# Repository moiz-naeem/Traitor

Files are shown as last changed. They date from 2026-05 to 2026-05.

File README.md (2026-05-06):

***

# Traitor Air Defence System 
Its a fully automatic desktop air defence turret powered by a Raspberry Pi Pico. 

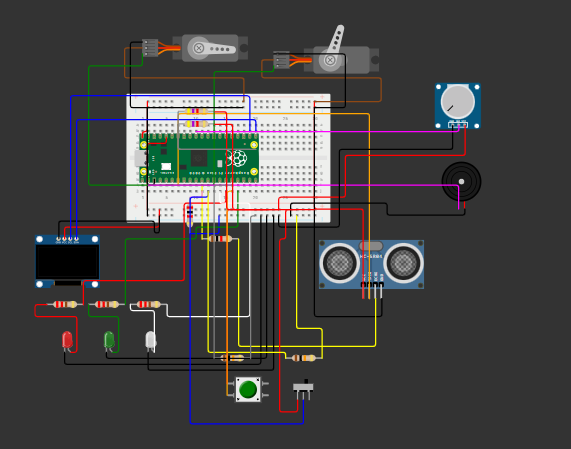
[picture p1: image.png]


Basically, this system spins a sensor around to look for enemys. If it sees something closer then the limit, it double checks to make sure its not a glitch. If the target is real, it sounds a loud alarm and uses a second servo to pull the trigger and launch a dart. You can also turn off the firing and just use it as a alarm.

## How it Works 
The code is written in MicroPython and uses a state machine. It has different moods:
* **IDLE:** System is armed but sleeping.
* **SCANNING:** The scan servo sweeps back and forth. The ultrasonic sensor send pulses to check distance.
* **CONFIRM:** If it spots something, it stops and checks 3 times to make sure the target is actually their.
* **ALERT:** FREAK OUT MODE! Red light turns on, buzzer screams and if your in LAUNCH mode, the trigger servo fires.
* **COOLDOWN:** Takes a 5 second break so it does not just keep shooting forever, then goes back to scanning.

## Hardware Components 
Here is the list of things you need to build this:
* **Raspberry Pi Pico** (Main brain)
* **2x Micro Servos** (One for looking around, one for the trigger)
* **1x HC-SR04 Ultrasonic Sensor** (The main sensor that acts as eyes of the system)
* **1x SSD1306 OLED Display (I2C)** (Shows real time state and sensor's data)
* **1x 5V Magnetic Buzzer** (For the alarm)
* **1x NPN Transistor (like 2N2222)** (Very important! Used as a switch so the buzzer does not burn out the Pico pin)
* **1x Potentiometer** (Twisty knob to change how far the sensor looks)
* **1x Push Button** (Main power switch)
* **1x Slide Switch** (To change between ALARM ONLY and LAUNCH mode)
* **3x LEDs** (Red for danger, Green for scanning, White for power)
* **Resistors:** 
  * 3x 220 Ohm (for LEDs)
  * 2x 10k Ohm (Pull-down for switches)
  * 2x 4.7k Ohm (Pull-up for OLED I2C)
  * 1x 1k Ohm & 1x 2k Ohm (Voltage divider to step down the 5V Echo pin to 3.3V so Pico does not break)

## Pin Mapping 
Make sure you wire everything exact like this or the code does not works. 

| Component | Pico Pin | Notes |
| :--- | :--- | :--- |
| **Scan Servo** | `GP3` | PWM out (50Hz) |
| **Trigger Servo** | `GP4` | PWM out (50Hz) |
| **Ultrasonic TRIG** | `GP5` | Sends the sound pulse |
| **Ultrasonic ECHO**| `GP8` | Hears the bounce (Voltage divider is amust here) |
| **Buzzer** | `GP1` | Connect to transistor base with 1k resistor |
| **Mode Switch** | `GP9` | Changes fire mode (needs 10k pull-down) |
| **Power Button** | `GP12` | Main on/off toggle |
| **Power LED (White)**| `GP10` | Shows if system is active |
| **Alert LED (Red)** | `GP11` | Turns on when target locked |
| **Scan LED (Green)** | `GP13` | Blinks when looking around |
| **OLED SCL** | `GP16` | I2C Clock (needs 4.7k pull-up to 3.3v) |
| **OLED SDA** | `GP17` | I2C Data (needs 4.7k pull-up to 3.3v) |
| **Potentiometer** | `GP26` | ADC to read the twisty knob |

## Setup Instructions 
1. Wire all the components on your breadboard using the pin mapping above. 
2. Make sure you put the 100uF capacitor across the 5V power rails so the servos dont crash the Pico when they move
3. Connect the Pico to your computer.
4. Open Thonny IDE.
5. Go to `Tools > Manage Packages` and install `micropython-ssd1306` so the screen works.
6. Copy the python code into a file called `main.py` on the Pico.
7. Unplug from computer, plug into battery bank, and press the power button to start defending your desk

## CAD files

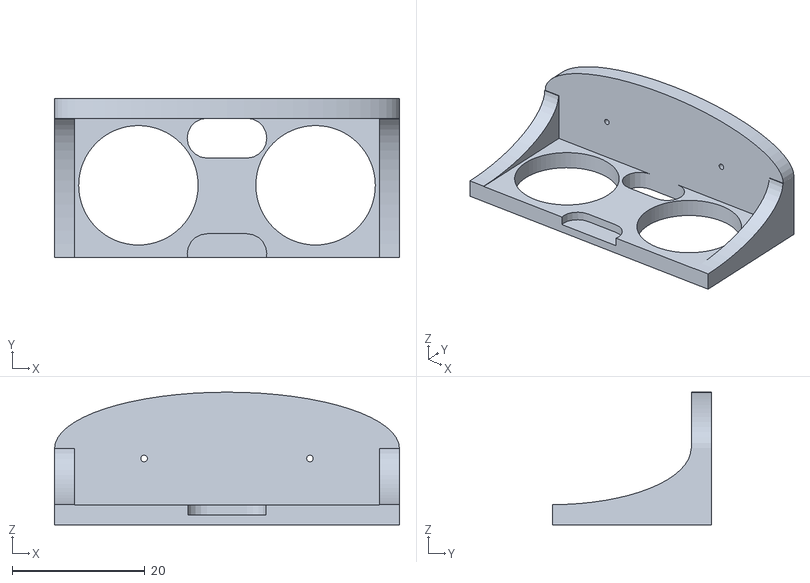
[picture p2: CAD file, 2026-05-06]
HC-SR04 - 9G micro servo bracket.stl
52.0 x 24.0 x 20.0

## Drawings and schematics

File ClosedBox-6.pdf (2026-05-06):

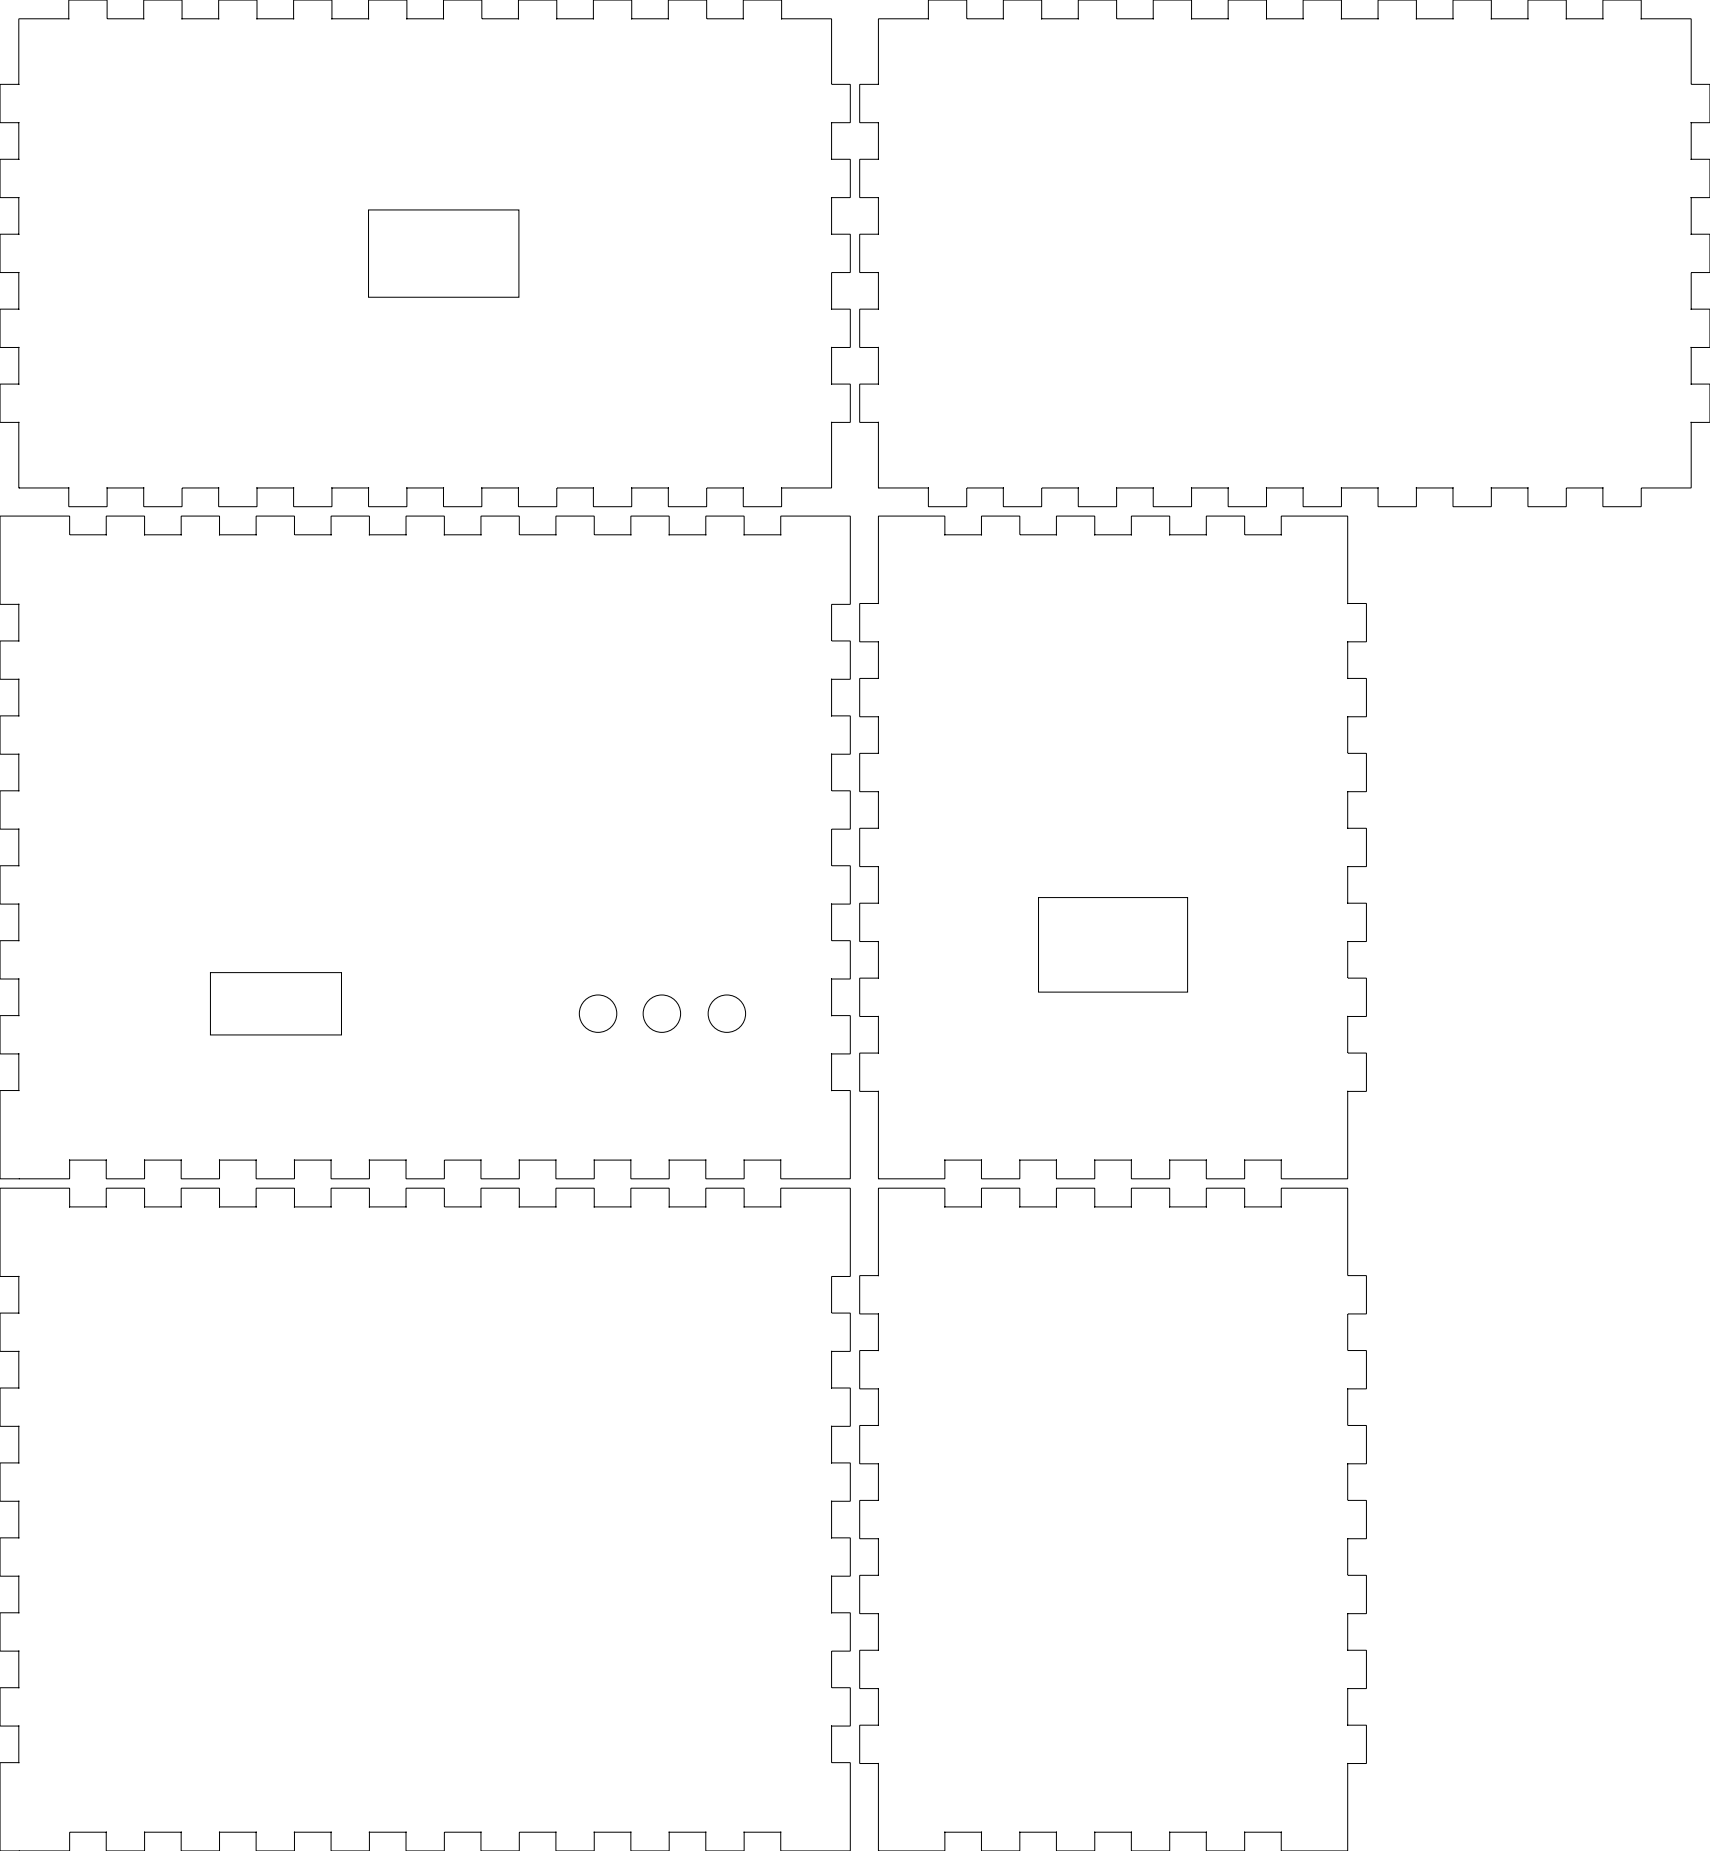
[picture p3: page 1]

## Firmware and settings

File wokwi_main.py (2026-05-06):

# ============================================================
#  Traitor Traitor Air Defence System — MicroPython Firmware
#  Hardware: Raspberry Pi Pico  
#  Author:   Moiz Ul Rehman
#
#  Below is my code for the air defence turret. 
#  Basically it spins ultrasonic sensor around to look for things in the way. 
#  If something gets to close, it double checks,
#  and sounds the alarm. If I flip the switch, it also moves a 
#  second servo to launch a dart at the detected obj 
#
#  Gpio mapping:
#    Pin 3  -> scanner servo that spins left and right 
#    Pin 4  -> launcher servo that pulls the trigger
#    Pin 5  -> ultrasonic trig 
#    Pin 8  -> ultrasonic echo 
#    Pin 1  -> buzzer for the alarm
#    Pin 9  -> slide switch to choose ALARM or LAUNCH mode
#    Pin 12 -> Big main power button
#    Pin 11 -> Red LED (danger light)
#    Pin 13 -> Green LED (scanning/safe light)
#    Pin 10 -> White LED (tells us system is turned on)
#    Pin 16 -> OLED screen SCL clock pin
#    Pin 17 -> OLED screen SDA data pin
#    Pin 26 -> potentiometer to change distance limit
# ============================================================

from machine import Pin, PWM, ADC, I2C
import time

# ============================================================
#  Screen stuff. 
#  Sometimes the screen library is missing depending on which IDE 
#  you are using and it crashes the whole code. So I put a try/except here. 
#  If it cant find the screen code, it just skips it and prints to the serial debig
# ============================================================
try:
    import ssd1306
    _HAS_SSD1306 = True
except ImportError:
    _HAS_SSD1306 = False
    print("[WARN] ssd1306 not found — OLED disabled")

# Setting up the servo motors. They need a 50 frequency to work right.
servo_scan    = PWM(Pin(3));  servo_scan.freq(50)
servo_trigger = PWM(Pin(4));  servo_trigger.freq(50)

# Trigger and echo of ultrasonic sensor 
trig = Pin(5, Pin.OUT)
echo = Pin(8, Pin.IN)    

# The buzzer needs a crazy high frequency to sound really annoying
buzzer = PWM(Pin(1))
buzzer.freq(2730)
buzzer.duty_u16(0) 

# Setting up all the leds, slider switch and power button
mode_sw = Pin(9, Pin.IN, Pin.PULL_DOWN)
btn_power = Pin(12, Pin.IN)
led_red   = Pin(11, Pin.OUT)
led_green = Pin(13, Pin.OUT)
led_power = Pin(10, Pin.OUT)

# I2C wires so the pico can talk to the oled, frq at 40kHz
try:
    i2c = I2C(0, sda=Pin(16), scl=Pin(17), freq=400000)
except Exception as e:
    i2c = None
    print(f"[WARN] I2C init failed: {e}")

# This is the twisty knob pin
pot = ADC(26)

# before proceeding , check if the screen is actually connected and working
HAS_OLED = False
if _HAS_SSD1306 and i2c is not None:
    try:
        oled = ssd1306.SSD1306_I2C(128, 64, i2c)
        HAS_OLED = True
        print("[BOOT] OLED OK")
    except Exception as e:
        print(f"[WARN] OLED failed: {e}")


def servo_set_us(pwm_obj, us):
    """
    Sets the servo position using microsecond pulse widths.
    microPython's duty_u16() takes 0-65535 siince the PWM frequency is 50Hz 
    a full period is 20000us. Formula: (Pulse / Period) * Max_Duty.
    """
    duty = int(us / 20000.0 * 65535)
    pwm_obj.duty_u16(duty)

def angle_to_us(degrees):
    """
    Maps a physical angle 0-180 to a PWM pulse width in microseconds.
    """
    degrees = max(0, min(180, degrees))
    # 500us -->  0 degres and 2500us --> 180 deg.
    return int(500 + (degrees / 180.0) * 2000) 


def get_distance_cm():
    """
    Calculates distance using the HC-SR04 ultrasonic sensor.
    P.S. : I foudn the math below in a doc blog but I forget where.
    Sound travels at 343m/s. The calculation for distance in cm is:
    distance = (time* speed of sound) / 2
    simplified constant: 1 / (0.0343 / 2) -. 58.3.
    """
    trig.value(0)
    time.sleep_us(2)
    trig.value(1)
    time.sleep_us(10)
    trig.value(0)

    #wait for echo to start or simply wait fr pulse to go high
    t0 = time.ticks_us()
    while echo.value() == 0:
        #we use ticks_diff instead of direct subtraction
        #cause it handles wrap-around automatically
        if time.ticks_diff(time.ticks_us(), t0) > 30000:
            return 999 # took too long so nothing is there

    #measure the duration of pulse
    start = time.ticks_us()
    while echo.value() == 1:
        if time.ticks_diff(time.ticks_us(), start) > 30000:
            return 999
    stop = time.ticks_us()

    return time.ticks_diff(stop, start) / 58.0

def oled_show(line1, line2="", line3=""):
    """
    displays three lines of text on the OLED screen.
    """
    if HAS_OLED:
        oled.fill(0) #clear the old stuff first, very imp
        oled.text(str(line1)[:16], 0, 8)
        oled.text(str(line2)[:16], 0, 28)
        oled.text(str(line3)[:16], 0, 48)
        oled.show()
    else:
        #if oled is disconnected we fallbackto the console.
        print(f"[OLED] {line1} | {line2} | {line3}")

def buzzer_on():
    """activates the buzzer at 50% duty cycle."""
    buzzer.duty_u16(32768)

def buzzer_off():
    """deactivates the buzzer"""
    buzzer.duty_u16(0)


def beep(times=1, on_ms=120, off_ms=100):
    """
    gnrates a sequence of short beeps solely for feedback purposes
    """
    for _ in range(times):
        buzzer_on();  time.sleep_ms(on_ms)
        buzzer_off(); time.sleep_ms(off_ms)

def get_threshold_cm():
    """
    eadspotentiometer and maps it to a distance range.
    default is 10cm
    """
    raw = pot.read_u16()
    return 10 + int((raw / 65535.0) * 140)

def get_mode():
    """ helper function to get current mode. 1--> Launch"""
    return "LAUNCH" if mode_sw.value() == 1 else "ALaRM"


# s etting up the rules for how the turret looks around
SWEEP_MIN_DEG  = 0      
SWEEP_MAX_DEG  = 180    
SWEEP_STEP_DEG = 3 #jump 3 deg at a time
STEP_DELAY_MS  = 40     

sweep_angle = 90        
sweep_dir   = 1         # 1 means go right -1 means go left

def sweep_step():
    """
    calculates and moves the scan servo by one increment.
    when it hits the edge it turns around
    """
    global sweep_angle, sweep_dir
    sweep_angle += sweep_dir * SWEEP_STEP_DEG
    if sweep_angle >= SWEEP_MAX_DEG:     # Reverse direction logic
        sweep_angle = SWEEP_MAX_DEG
        sweep_dir = -1
    elif sweep_angle <= SWEEP_MIN_DEG:
        sweep_angle = SWEEP_MIN_DEG
        sweep_dir = 1
    servo_set_us(servo_scan, angle_to_us(sweep_angle))
    return sweep_angle

def trigger_home():
    """resets the trigger servo to the neutral/home position. --> 90"""
    servo_set_us(servo_trigger, angle_to_us(90))

def full_home():
    """sesets all servos to neutral/home pos and initialies sweep variables."""
    global sweep_angle, sweep_dir
    sweep_angle = 90
    sweep_dir   = 1
    servo_set_us(servo_scan,    angle_to_us(90))
    servo_set_us(servo_trigger, angle_to_us(90))

# I made this part so the button works better. 
# Sometimes buttons glitch and press twice super fast.
# This makesit wait a quarter second before it counts a new press.
system_active = False
_btn_prev     = 0
_btn_last_ms  = 0
def check_button():
    global system_active, _btn_prev, _btn_last_ms
    
    curr_val = btn_power.value()
    curr_ms = time.ticks_ms()
    
    if curr_val == 1 and _btn_prev == 0:
        if time.ticks_diff(curr_ms, _btn_last_ms) > 250:
            system_active = not system_active
            beep(1, 50, 0) 
            _btn_last_ms = curr_ms #reset timer after valid press
            print(f"[POWER] System is now {'ON' if system_active else 'OFF'}")
            
    _btn_prev = curr_val

# ============================================================
# Main State Machine
# ============================================================

STATE_IDLE     = 0
STATE_SCANNING = 1
STATE_CONFIRM  = 2
STATE_ALERT    = 3
STATE_COOLDOWN = 4

state         = STATE_IDLE
confirm_count = 0
detected_dist = 0.0
locked_angle  = 90

led_power.value(1)
led_red.value(0)
led_green.value(0)

full_home()
beep(times=2, on_ms=80, off_ms=80)   

oled_show("AIR DEFENCE", "Traitor READY")
time.sleep_ms(1500)

print("=" * 42)
print("[BOOT] Traiotr Air Defence")
print(f"[BOOT] OLED  : {'OK' if HAS_OLED else 'FAILED'}")
print(f"[BOOT] I2C   : Bus 0  SDA=GP17  SCL=GP16")
print(f"[BOOT] Mode  : {get_mode()}")
print("=" * 42)


# The main brain loop. It goes forever.
while True:
    check_button() # check if I pushed power

    # If I turned it off ,turn off all lights and stay sleeping
    if not system_active:
        led_power.value(0)
        led_red.value(0)
        led_green.value(0)
        buzzer_off()
        oled_show("SYSTEM OFF", "Press button")
        state = STATE_IDLE 
        time.sleep_ms(100)
        continue # skip the rest of the code and loop back to start

    led_power.value(1) # power is on

    if state == STATE_IDLE:
        # Just hanging out waiting to start scanning
        led_green.value(1)
        led_red.value(0)
        oled_show("[ IDLE ]", "System armed", f"Mode:{get_mode()}")
        time.sleep_ms(400)
        state = STATE_SCANNING
        print("[STATE] → SCANNING")

    elif state == STATE_SCANNING:
        # Traitor starts actively looking for targets
        current_angle = sweep_step()
        threshold     = get_threshold_cm() # read the knob for threshold everytime
        dist          = get_distance_cm()
        mode          = get_mode()

        led_green.value(1 if (current_angle % 30) < 15 else 0)
        led_red.value(0)

        oled_show(
            f"[{mode}] SCAN",
            f"D:{dist:.0f}cm T:{threshold}cm",
            f"A:{current_angle:03d} {'>>>' if sweep_dir > 0 else '<<<'}"
        )
        print(f"[SCAN] angle={current_angle}  dist={dist:.1f}cm  thresh={threshold}cm")

        #if we detct object within our range we intitalise trigger but we
        # dont immediately lock, more about it in STATE_CONFIRM
        if dist <= threshold:
            confirm_count = 1
            detected_dist = dist
            locked_angle  = current_angle 
            state = STATE_CONFIRM
            print(f"[STATE] → CONFIRM  dist={dist:.1f}cm  angle={current_angle}deg")

        time.sleep_ms(STEP_DELAY_MS)

    elif state == STATE_CONFIRM:
        # Ultrasonic sensors often give fales low readings due to air 
        # currents or odd angles. therefore we made the decision to require 3
        # consecutive readings below the threshold before engaging the alarm.
        threshold = get_threshold_cm()
        dist      = get_distance_cm()

        led_green.value(1)
        led_red.value(0)

        oled_show(
            "CONFIRMING...",
            f"D:{dist:.0f}cm T:{threshold}cm",
            f"Reading {confirm_count}/3"
        )
        print(f"[CONFIRM] dist={dist:.1f}cm  count={confirm_count}/3")

        if dist <= threshold:
            confirm_count += 1
            detected_dist = dist
            # If we see it 3 times, its real. Sound the alarm
            if confirm_count >= 3:
                state = STATE_ALERT
                print(f"[STATE] → ALERT  dist={detected_dist:.1f}cm  angle={locked_angle}deg")
        else:
            # false alarm, we go back to looking around
            confirm_count = 0
            state = STATE_SCANNING
            print("[STATE] → SCANNING")

        time.sleep_ms(STEP_DELAY_MS)

    elif state == STATE_ALERT:
        #engagement state
        led_green.value(0)
        led_red.value(1)

        mode = get_mode()

        #aim at the specific angle where the target was confirmed
        servo_set_us(servo_scan, angle_to_us(locked_angle))

        if mode == "LAUNCH":
            #fire the trigger servo
            servo_set_us(servo_trigger, angle_to_us(locked_angle))
            oled_show("!! DETeCTED !!", f"D:{detected_dist:.0f}cm Az:{locked_angle}", "LAUNCH ENaBLED")
            print(f"[ALERT] LAUnCH  dist={detected_dist:.1f}cm  angel={locked_angle}deg")
        else:
            # Just yell, dont fire
            servo_set_us(servo_trigger, angle_to_us(90))
            oled_show("!! DETECTED !!", f"D:{detected_dist:.0f}cm Az:{locked_angle}", "ALARM ONLY")
            print(f"[ALERT] Alarm   dist={detected_dist:.1f}cm  angel={locked_angle}deg")

        buzzer_on()
        time.sleep_ms(2000)
        buzzer_off()

        state = STATE_COOLDOWN
        print("[STATE] → COOLDOWN")

    elif state == STATE_COOLDOWN:
        # prevents the turret from jittering or firing immediately again.
        # also provides us with enough time to clear the area and 
        # for the motor to return to home before this it'd keep yellign and detecting
        # same obj again and again and servos would start continuously movinf around.
        led_red.value(1)
        led_green.value(0)
        buzzer_off()


        for i in range(5, 0, -1):
            oled_show("[ COOLDOWN ]", f"Resume in {i}s", f"Az:{locked_angle:03d} locked")
            print(f"[COOLDOWN] {i}s  scan locked at {locked_angle}deg")
            time.sleep_ms(1000)

        trigger_home()
        led_red.value(0)
        confirm_count = 0
        state = STATE_SCANNING
        print(f"[STATE] → SCANNING from {sweep_angle}deg")

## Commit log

2026-04-20 Main traitor defence system code and oled driver
2026-04-21 Ultrasonic trig, echo r1 and buzzer pin updated
    [wokwi_main.py]
2026-04-22 Pushdown button added for power and switch now handles mode
2026-05-06 Updated the diagram wiring to match the final pin selection
